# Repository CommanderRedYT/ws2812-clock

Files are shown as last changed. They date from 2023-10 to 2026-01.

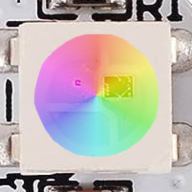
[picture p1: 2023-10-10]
firmware/webapp/src/android-chrome-192x192.png

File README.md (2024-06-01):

# ws2812-clock

This is a project I started when a teacher told us to do a "simple" project. This project is a PCB containing 232
WS2812B LEDs that are controlled via a ESP32. The current version (v2) does not have a RTC module and entirely relies on
NTP. The PCB comes with a USB-C port which you can also use to program the port (No power delivery tho, only normal USB 5V).
The PCB also has a barrel jack that has reverse polarity protection using a P-FET. I also added a footprint for both a
SHT-30 and a BME-280 sensor. However, with how warm the LEDs get with high brightness, the temperature reading are not
accurate if you are looking for the room temperature.

## Features
- 232 WS2812B LEDs
- ESP32
- USB-C with programmer (CH343)
- Barrel jack with reverse polarity protection

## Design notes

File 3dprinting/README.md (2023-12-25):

# 3D Printing Files

The models are created using Fusion 360.

## Printing

I recommend printing with the hexagon infill pattern as it will look really cool when the clock is on!

## Notes
- As of now, the model is kind of cut in the middle so it can be printed on the Prusa printers.
- Also, some case-features are not fully working yet.

## Known problems
- Buttons not working --> Make them cylinders that can slide up and down instead of making it print-in-place and "bendable"

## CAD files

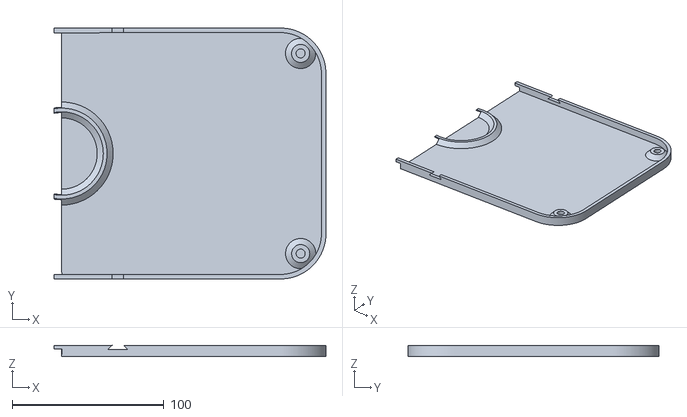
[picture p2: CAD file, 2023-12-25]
3dprinting/v22/Lower Case Right.stl
179.4 x 165.5 x 7.50

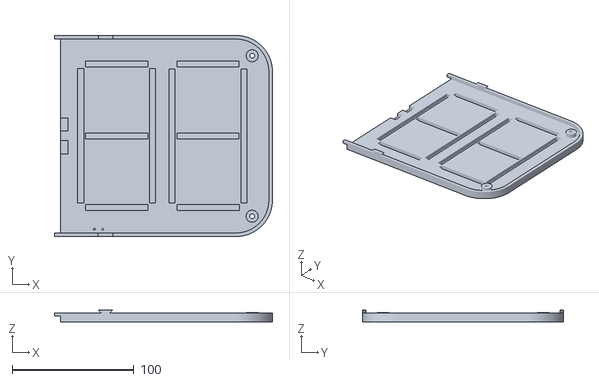
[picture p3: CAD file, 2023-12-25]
3dprinting/v22/Upper Case Right.stl
179.4 x 165.5 x 10.0

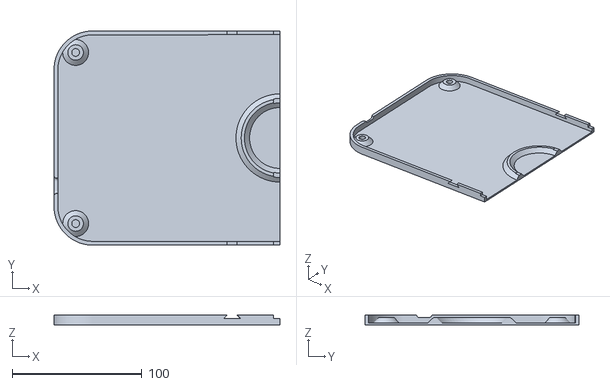
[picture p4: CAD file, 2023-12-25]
3dprinting/v22/Lower Case Left.stl
174.3 x 165.3 x 7.50

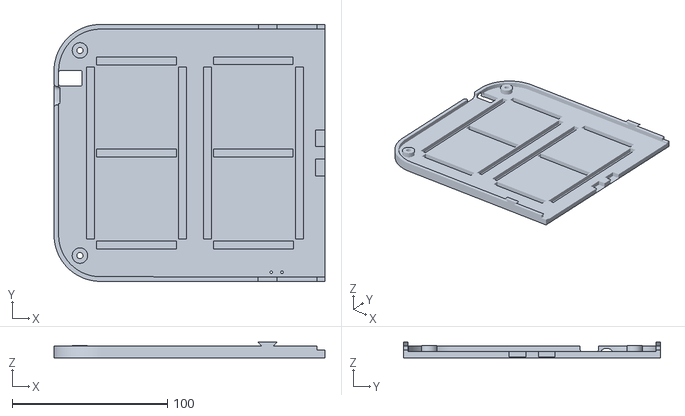
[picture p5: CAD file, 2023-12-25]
3dprinting/v22/Upper Case Left.stl
174.3 x 165.3 x 10.0

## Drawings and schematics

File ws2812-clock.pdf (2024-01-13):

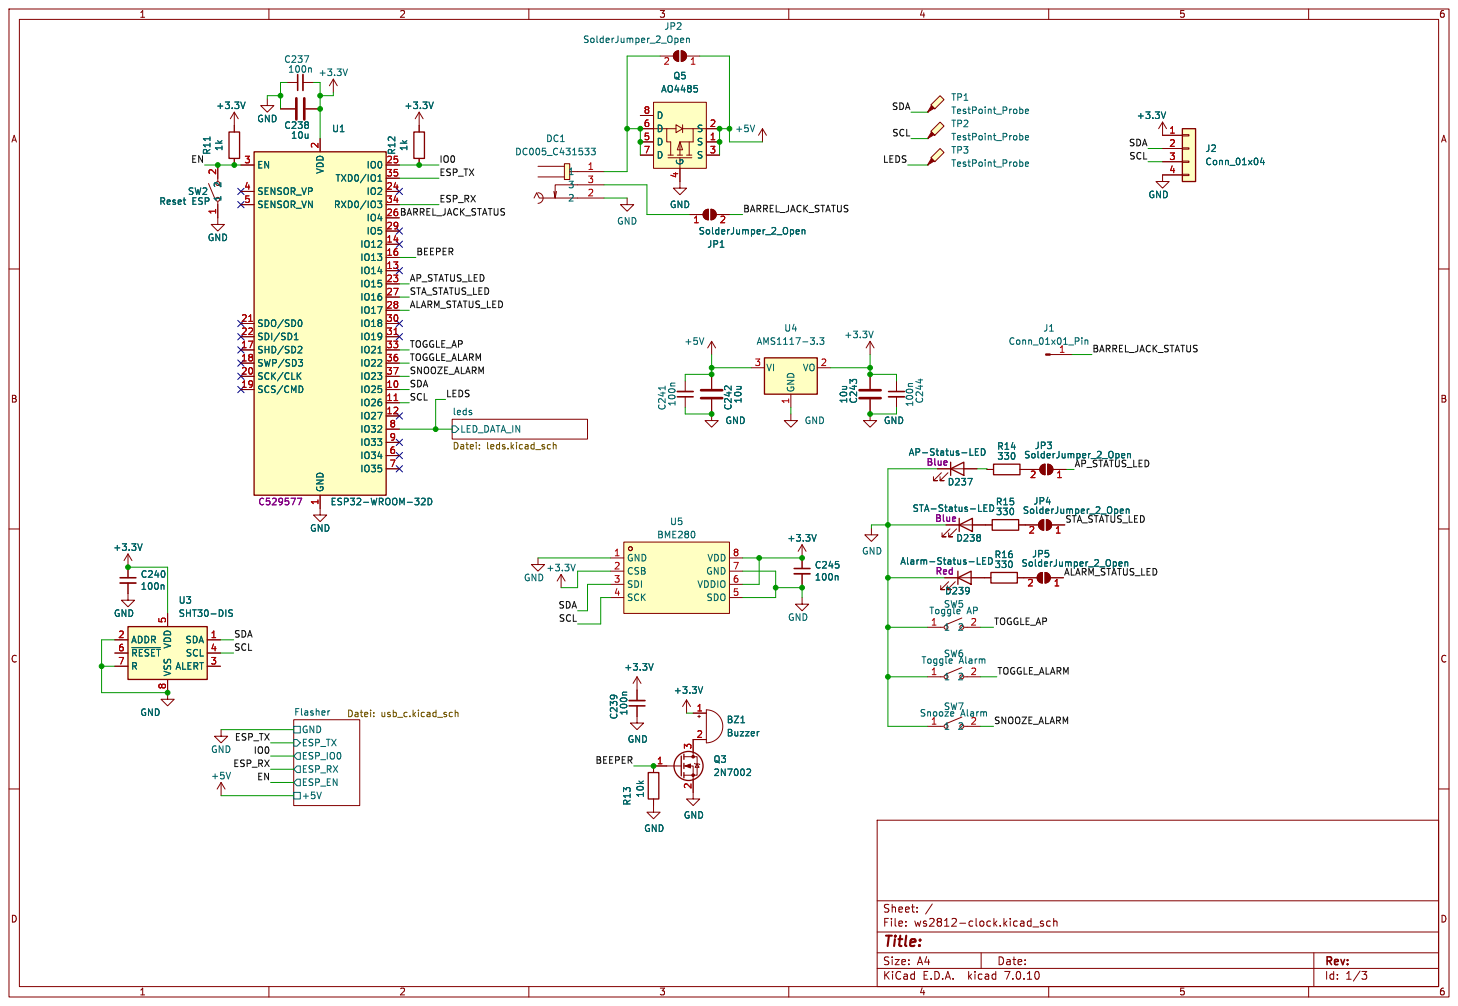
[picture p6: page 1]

2 SCK/CLK 20 SDO/SD0 21 SDI/SD1 22

Red D238 STA-Status-LED

Id: 1/3 Title: File: ws2812-clock.kicad_sch Sheet: /

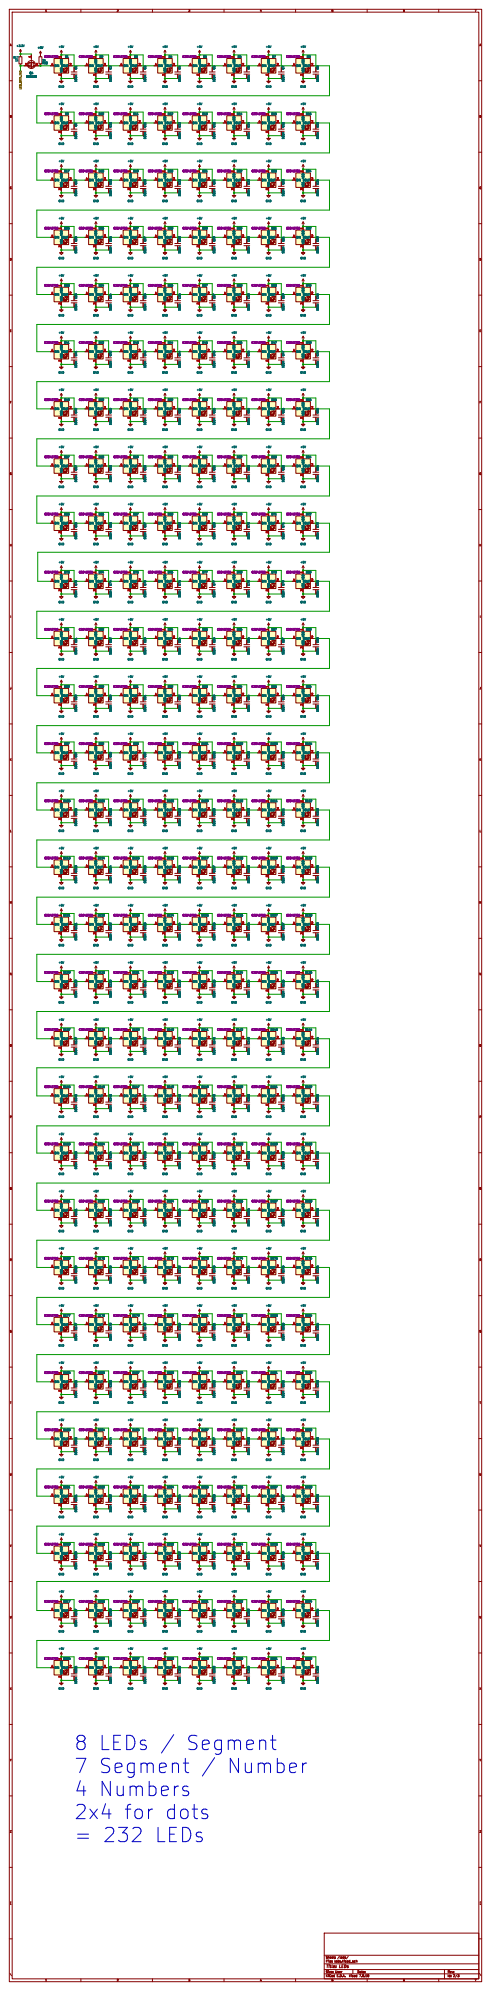
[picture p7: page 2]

3 DIN 4 C2843785 D9 C226 100n GND GND GND GND
RGB VDD

3 DIN 4 C2843785 D75 +5V +5V +5V GND GND GND

File: leds.kicad_sch Sheet: /leds/
Id: 2/3 Title: LEDs

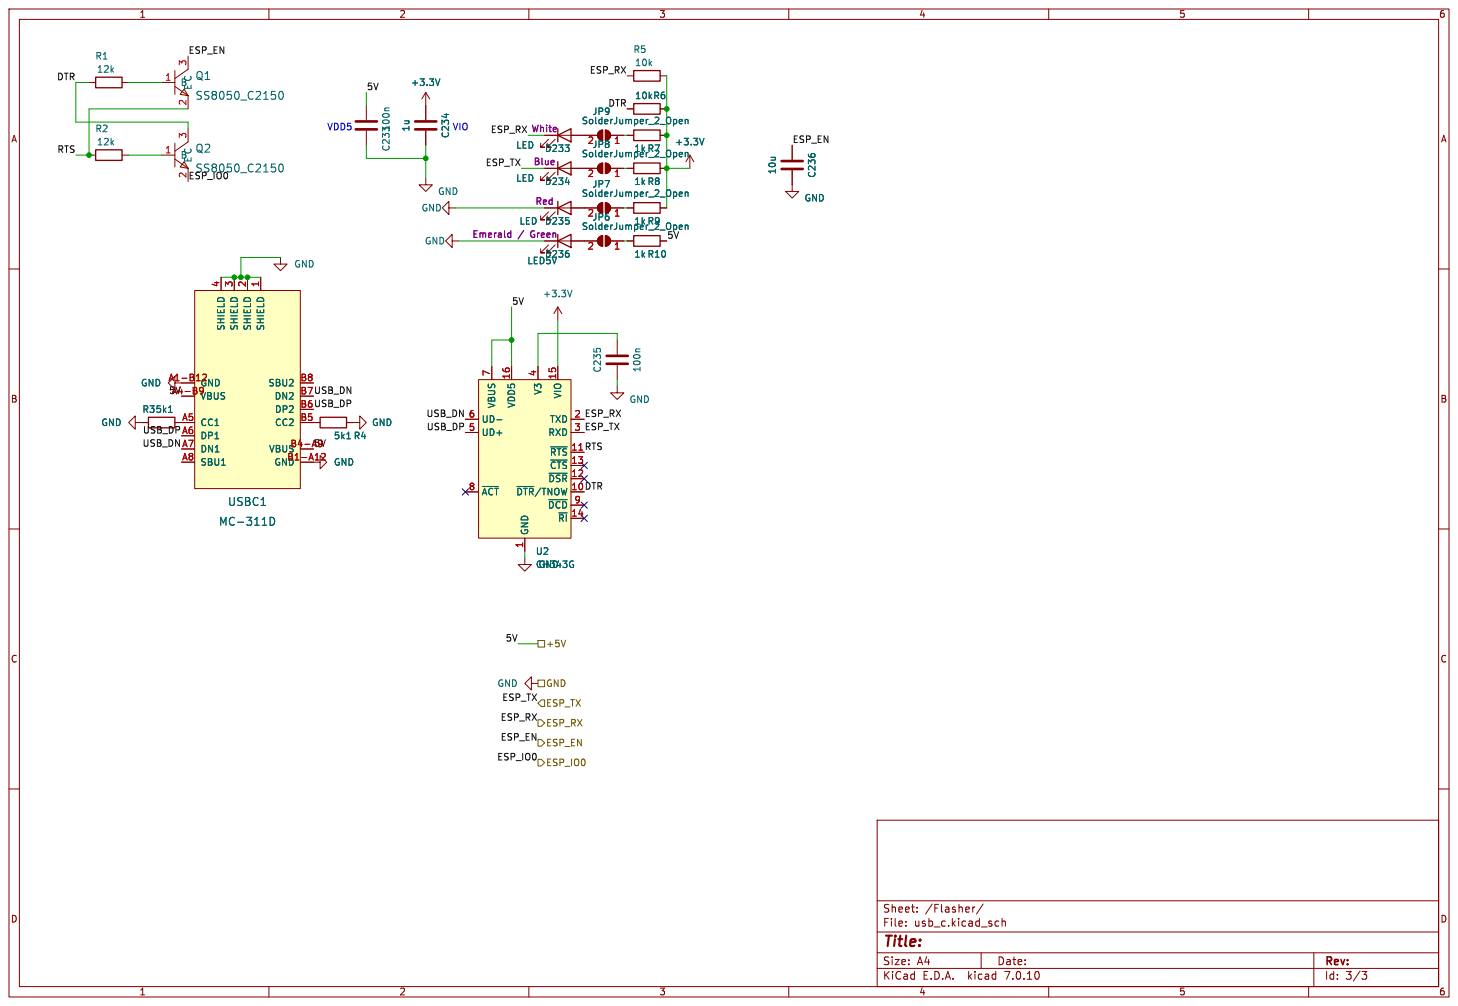
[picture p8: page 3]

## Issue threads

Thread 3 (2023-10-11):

Enhancement mqtt discovery

dschiedsch, 2023-10-11:
Add a mqtt autodiscovery feature so that HomeAssistant can deiscover the device automatically
https://www.home-assistant.io/integrations/mqtt/#mqtt-discovery

CommanderRedYT, 2023-10-12:
What should it be discovered as?
Should there also be write-able stats?

dschiedsch, 2023-10-12:
three sensors (temp, humidity, pressure)
i don't think we need writeable stats via mqtt

here is an example of a mqtt config from a temp sensor I use

`{"name":"Home Buttons 83653D Temperature","uniq_id":"HBTNS-2308-032-83653D_temperature","stat_t":"homebuttons/Home Buttons 83653D/temperature","dev_cla":"temperature","unit_of_meas":"°C","exp_aft":660,"dev":{"ids":["HBTNS-2308-032-83653D"]}}`

and here of a humidity sensor:

`{"name":"Home Buttons 83653D Humidity","uniq_id":"HBTNS-2308-032-83653D_humidity","stat_t":"homebuttons/Home Buttons 83653D/humidity","dev_cla":"humidity","unit_of_meas":"%","exp_aft":660,"dev":{"ids":["HBTNS-2308-032-83653D"]}}`

dschiedsch, 2023-10-12:
also I would like the mqtt update rate to be either settable or at least slower than the 1sec it is now, otherwise it will just spam the mqtt channel

Closed 2023-11-26.

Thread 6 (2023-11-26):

BME280 pressure sensor scaling off by x100

dschiedsch, 2023-11-26:
The BME280 pressure sensor scaling is off by a factor of 100
the value published as pressure in hpa should be divided by 100 to be correct
eg "pressure": 97186.78 should be "pressure": 971.8678,

Closed 2023-11-26.

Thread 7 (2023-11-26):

home assistant brightness control not working completely

dschiedsch, 2023-11-26:
I can control brightness from ha, however if i switch off and on it returns to some default brightness and not the brightness i set before
also ha doesn't display the current brightness at all

CommanderRedYT, 2023-11-26:
I am not entirely sure why it doesn't display the brightness, but I can try debugging it. The whole brightness thing was hours of figuring things out. Do you maybe have a working brightness slider config you could share? Then I could just replicate that

dschiedsch, 2023-11-26:
here is the topic from another light:
{
  "availability": [
    {
      "topic": "zigbee2mqtt/bridge/state"
    }
  ],
  "brightness": true,
  "brightness_scale": 254,
  "command_topic": "zigbee2mqtt/Schlafzimmer/set",
  "device": {
    "identifiers": [
      "zigbee2mqtt_0x000d6f0016bcd3e9"
    ],
    "manufacturer": "OSRAM",
    "model": "Zigbee 3.0 DALI CONV LI dimmer for DALI-based luminaires (only one device) (4062172044776_1)",
    "name": "Schlafzimmer",
    "sw_version": "1.0.0.8-6.5.5.b"
  },
  "effect": true,
  "effect_list": [
    "blink",
    "breathe",
    "okay",
    "channel_change",
    "finish_effect",
    "stop_effect"
  ],
  "json_attributes_topic": "zigbee2mqtt/Schlafzimmer",
  "name": "Schlafzimmer",
  "schema": "json",
  "state_topic": "zigbee2mqtt/Schlafzimmer",
  "unique_id": "0x000d6f0016bcd3e9_light_zigbee2mqtt"
}

Closed 2023-11-26.

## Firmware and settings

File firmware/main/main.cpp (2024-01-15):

constexpr const char * const TAG = "main";

// esp-idf includes
#include <esp_log.h>
#include <freertos/FreeRTOS.h>
#include <freertos/task.h>

// esp-idf optional includes
#if defined(CONFIG_ESP_TASK_WDT_PANIC) || defined(CONFIG_ESP_TASK_WDT)
#include <esp_task_wdt.h>
#endif

// local includes
#include "utils/config.h"
#include "utils/global_lock.h"
#include "utils/tasks.h"

/*--- Config Flag Error Handling ---*/
#if defined(HARDWARE_USE_SHT30) && defined(HARDWARE_USE_BME280)

#error "BME280 and SHT30 are mutually exclusive."

#endif

#if !defined(HARDWARE_WS2812B_PIN) || !defined(HARDWARE_WS2812B_COUNT)

#error "WS2812B pin and count must be defined."

#endif

using namespace std::chrono_literals;

extern "C" [[noreturn]] void app_main()
{
    ESP_LOGI(TAG, "app_main()");

    /*--- Task Watchdog ---*/
#if defined(CONFIG_ESP_TASK_WDT_PANIC) || defined(CONFIG_ESP_TASK_WDT)
    {
        const auto taskHandle = xTaskGetCurrentTaskHandle();
        if (!taskHandle)
        {
            ESP_LOGE(TAG, "could not get handle to current main task!");
        }
        else if (const auto result = esp_task_wdt_add(taskHandle); result != ESP_OK)
        {
            ESP_LOGE(TAG, "could not add main task to watchdog: %s", esp_err_to_name(result));
        }
    }
#endif


    /*--- Settings ---*/
    if (const auto result = configs.init("ws2812-clock"); result != ESP_OK)
    {
        ESP_LOGE(TAG, "config_init_settings() failed with %s", esp_err_to_name(result));

        while (true)
        {
            vTaskDelay(1000);
        }
    }
    else
        ESP_LOGI(TAG, "config_init_settings() succeeded");


    /*--- Global Lock ---*/
    global::global_lock.construct();
    ESP_LOGI(TAG, "global lock constructed");


    /*--- Task Manager ---*/
    for (const auto& task : tasks)
        task.setup();

#if defined(CONFIG_ESP_TASK_WDT_PANIC) || defined(CONFIG_ESP_TASK_WDT)
    if (const auto result = esp_task_wdt_reset(); result != ESP_OK)
        ESP_LOGE(TAG, "esp_task_wdt_reset() failed with %s", esp_err_to_name(result));
#endif

    espchrono::millis_clock::time_point lastTaskPush = espchrono::millis_clock::now();

    while (true)
    {
        for (auto& task : tasks)
        {
            task.loop();

#if defined(CONFIG_ESP_TASK_WDT_PANIC) || defined(CONFIG_ESP_TASK_WDT)
            if (const auto result = esp_task_wdt_reset(); result != ESP_OK)
                ESP_LOGE(TAG, "esp_task_wdt_reset() failed with %s", esp_err_to_name(result));
#endif
        }

        if (espchrono::ago(lastTaskPush) > 1s)
        {
            lastTaskPush = espchrono::millis_clock::now();
            sched_pushStats(false);
        }

        vTaskDelay(1);
    }
}

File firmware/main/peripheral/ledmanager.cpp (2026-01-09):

#include "ledmanager.h"

constexpr const char * const TAG = "ledmanager";

// system includes
#include <format>

// 3rdparty lib includes
#include <FastLED.h>
#include <espchrono.h>
#include <recursivelockhelper.h>

// local includes
#include "communication/ota.h"
#include "peripheral/ledhelpers/ledanimation.h"
#include "utils/config.h"
#include "utils/espclock.h"

using namespace std::chrono_literals;

namespace ledmanager {

cpputils::DelayedConstruction<LedManager> ledManager;

cpputils::DelayedConstruction<espcpputils::recursive_mutex_semaphore> led_lock;

namespace {
LedArray leds;

bool calculateLedVisibility()
{
    if (!configs.ledAnimationEnabled.value())
    {
        return false;
    }

    if (configs.showUnsyncedTime.value())
    {
        return true;
    }

    if (espclock::isSynced())
    {
        return true;
    }

    return false;
}

bool isInSecondaryBrightnessTimeRange()
{
    const auto now = espchrono::local_clock::now();
    const auto dt = toDateTime(now);
    const auto secondaryBrightnessMode = configs.secondaryBrightnessMode.value();

    if (secondaryBrightnessMode == SecondaryBrightnessMode::Off)
    {
        ESP_LOGD(TAG, "secondaryBrightnessMode is Off");
        return false;
    }

    if (secondaryBrightnessMode == SecondaryBrightnessMode::UseRange)
    {
        const auto secondaryBrightnessStart = configs.secondaryBrightnessTimeRange.start.value(); // seconds32
        const auto secondaryBrightnessEnd = configs.secondaryBrightnessTimeRange.end.value();    // seconds32

        const auto startHour = secondaryBrightnessStart / 3600;
        const auto startMinute = (secondaryBrightnessStart % 3600) / 60;
        const auto endHour = secondaryBrightnessEnd / 3600;
        const auto endMinute = (secondaryBrightnessEnd % 3600) / 60;

        if (startHour > endHour || (startHour == endHour && startMinute > endMinute))
        {
            // over midnight
            if ((dt.hour >= startHour.count() || dt.hour < endHour.count()) ||
                (dt.hour == startHour.count() && dt.minute >= startMinute.count()) ||
                (dt.hour == endHour.count() && dt.minute < endMinute.count()))
            {
                return true;
            }

            return false;
        }

        // same day
        if ((dt.hour >= startHour.count() && dt.hour < endHour.count()) ||
            (dt.hour == startHour.count() && dt.minute >= startMinute.count()) ||
            (dt.hour == endHour.count() && dt.minute < endMinute.count()))
        {
            return true;
        }

        return false;
    }

    if (secondaryBrightnessMode == SecondaryBrightnessMode::UseSunriseSunset)
    {
        return espclock::isNight();
    }

    return false;
}

bool barrel_jack_connected()
{
    // floating when not connected, pull down when connected
    static bool gpio_initialized = false;

    constexpr auto barrel_jack = static_cast<gpio_num_t>(HARDWARE_BARREL_JACK_PIN);

    if (!gpio_initialized)
    {
        // TODO: Test if this actually works
        gpio_config_t io_conf;
        io_conf.intr_type = GPIO_INTR_DISABLE;
        io_conf.mode = GPIO_MODE_INPUT;
        io_conf.pin_bit_mask = 1ULL << HARDWARE_BARREL_JACK_PIN;
        io_conf.pull_down_en = GPIO_PULLDOWN_DISABLE;
        io_conf.pull_up_en = GPIO_PULLUP_ENABLE;
        if (const auto res = gpio_config(&io_conf); res != ESP_OK)
        {
            ESP_LOGE(TAG, "Failed to configure GPIO: %d", res);
            return false;
        }

        gpio_initialized = true;
    }

    return gpio_get_level(barrel_jack) == 0;
}

} // namespace

void LedManager::handleVoltageAndCurrent()
{
    // const auto now = espchrono::millis_clock::now();
    const auto brightness = configs.ledBrightness.value();
    const auto secondaryBrightness = configs.ledSecondaryBrightness.value();
    const auto inSecondaryBrightnessTimeRange = isInSecondaryBrightnessTimeRange();

    ESP_LOGD(TAG, "brightness: %d, secondaryBrightness: %d, inSecondaryBrightnessTimeRange: %d", brightness, secondaryBrightness, inSecondaryBrightnessTimeRange);

    const uint8_t brightnessTarget = !m_visible ? 0 : inSecondaryBrightnessTimeRange ? secondaryBrightness : brightness;

    constexpr float fadeFactor = 0.9f;
    m_brightness = m_brightness * fadeFactor + brightnessTarget * (1.0f - fadeFactor);

    // if difference is less than 1, set to target
    if (std::abs(m_brightness - brightnessTarget) < 1)
    {
        m_brightness = brightnessTarget;
    }

    FastLED.setBrightness(m_brightness);

    if (barrel_jack_connected())
    {
        // increase current
        // 5V, 8A
        FastLED.setMaxPowerInVoltsAndMilliamps(5, configs.ledMilliAmpereBarrelJack.value());
    }
    else
    {
        // 5V, 3A
        FastLED.setMaxPowerInVoltsAndMilliamps(5, configs.ledMilliAmpereUsbC.value());
    }
}

void begin()
{
    led_lock.construct();

    FastLED.addLeds<WS2812B, HARDWARE_WS2812B_PIN, HARDWARE_WS2812B_COLOR_ORDER>(leds.data(), leds.size());

    FastLED.setCorrection(TypicalSMD5050);

    FastLED.setDither(0);

    FastLED.clear();

    // Digit 1: LED_1 -> LED_56 => start 0, length 56
    // Digit 2: LED_57 -> LED_112 => start 56, length 56
    // Upper Dot: LED_113 -> LED_116 => start 112, length 4
    // Lower Dot: LED_117 -> LED_120 => start 116, length 4
    // Digit 3: LED_121 -> LED_176 => start 120, length 56
    // Digit 4: LED_177 -> LED_232 => start 176, length 56

    ledManager.construct(LedManager{
        {
            SevenSegmentDigit{leds.data() + 0, 56},
            SevenSegmentDigit{leds.data() + 56, 56},
            SevenSegmentDigit{leds.data() + 120, 56},
            SevenSegmentDigit{leds.data() + 176, 56},
        },
        ClockDot{ClockDot::Top, leds.data() + 112, 4},
        ClockDot{ClockDot::Bottom, leds.data() + 116, 4},
    });

    for (auto& digit : ledManager->digits)
    {
        digit.setChar('1');
    }
}

void update()
{
    espcpputils::RecursiveLockHelper guard{led_lock->handle};

    /*
    if (ota::isInProgress()) // Prevent guru meditation error because of rmt inline not in IRAM
        return;
    */

    if (ledManager.constructed())
    {
        ledManager->setVisible(calculateLedVisibility());

        ledManager->render();

        ledManager->handleVoltageAndCurrent();

        FastLED.show();
    }
}
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

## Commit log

2023-09-14 Updated PCB
    [ws2812-clock-CuBottom.gbr, ws2812-clock-CuTop.gbr, ws2812-clock-EdgeCuts.gbr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]
2023-09-14 Update mosfet circuit
    [ws2812-clock.kicad_sch]
2023-09-22 Fixed PCB trace
    [ws2812-clock-CuBottom.gbr, ws2812-clock-CuTop.gbr, ws2812-clock-EdgeCuts.gbr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]
2023-09-23 More fixes
    [ws2812-clock-CuBottom.gbr, ws2812-clock-CuTop.gbr, ws2812-clock-EdgeCuts.gbr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]
2023-10-10 Initial commit for firmware
    [partitions.csv]
2023-12-17 PCB rework (ordered)
    [usb_c.kicad_sch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]
2023-12-25 Add stl files
    [Lower Case Left.stl, Lower Case Right.stl, Upper Case Left.stl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]
2024-01-12 Update pcb
    [ws2812-clock-CuBottom.gbr, ws2812-clock-CuTop.gbr, ws2812-clock-EdgeCuts.gbr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]
2024-01-13 Implement barrel jack detection and milli-ampere configs
2024-11-30 Fix brightness not reaching its target
    [ledmanager.cpp]
2026-01-09 Refactor led code to run smoother + fix clock dot bug
    [ledmanager.cpp]
